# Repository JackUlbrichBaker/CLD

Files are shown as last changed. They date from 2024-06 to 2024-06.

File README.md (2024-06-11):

### Welcome to the Can LED Driver Git repo!

This is an STM32 based smart load switch that is capable of driving up to 60A at 20V (ignoring thermals)
Currently it is just a hardware repo - software TBC.  I know it is overkill but that is more fun than simplicity :seal:
<details open>
<summary>PCB: </summary>



</details>

<details open>
<summary>Schematic: </summary>



</details>

- [x] Hardware schematic
- [x] PCB layed out 
- [ ] PCB routed
- [ ] PCB ordered and populated
- [ ] Software written
- [ ] software tested

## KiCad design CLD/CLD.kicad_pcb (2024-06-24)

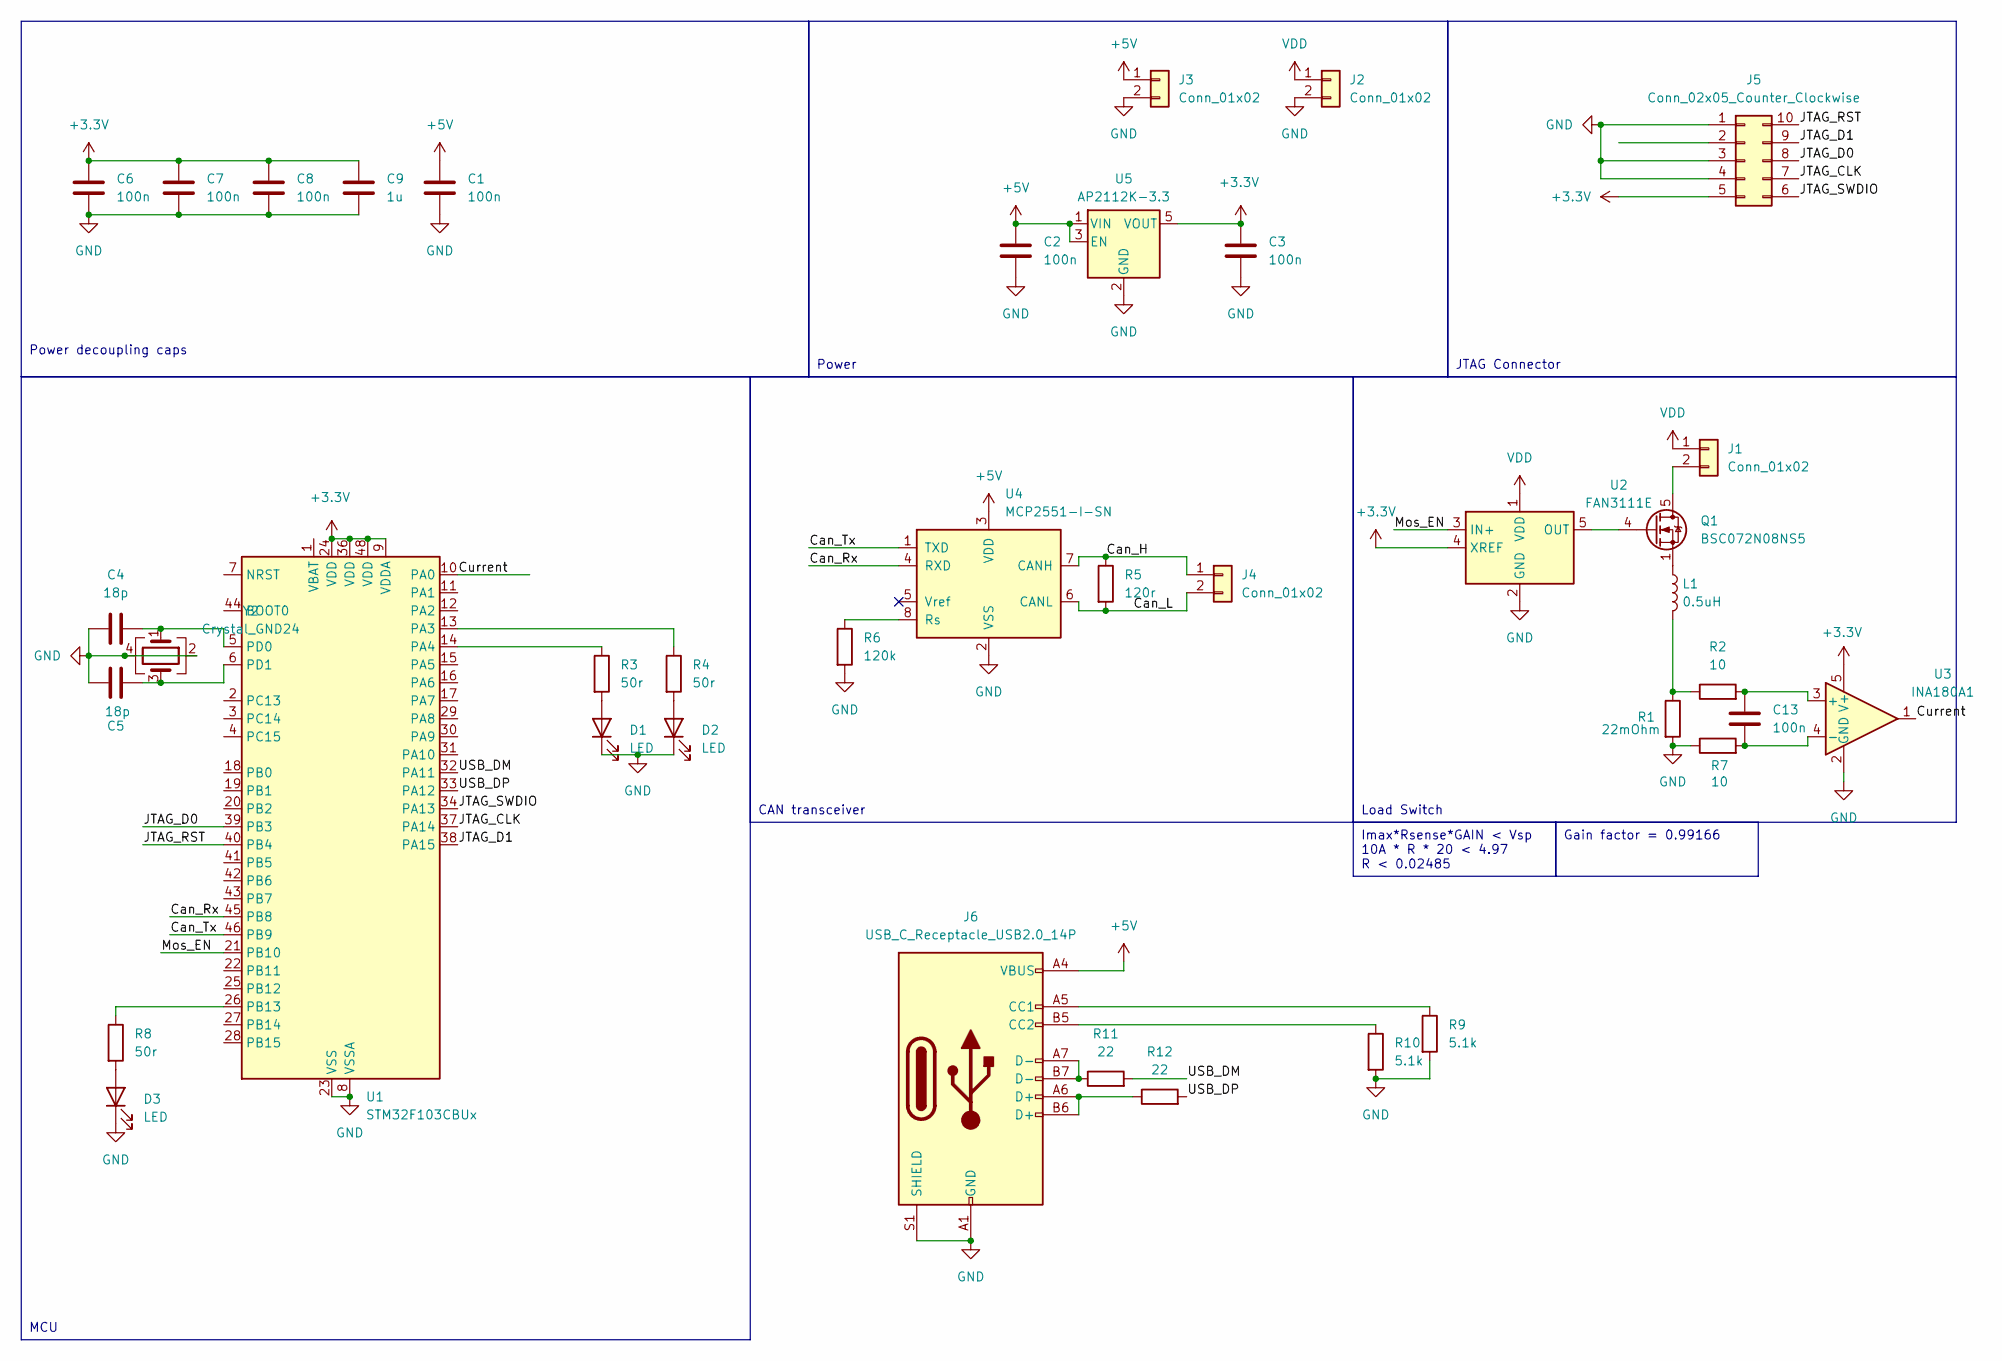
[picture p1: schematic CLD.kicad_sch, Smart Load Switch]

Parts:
C1, C2, C3, C6, C7, C8, C13: 100n; C_0603_1608Metric
C4, C5: 18p; C_0603_1608Metric
C9: 1u; C_0603_1608Metric
D1, D2, D3: LED; D_0603_1608Metric
J1, J2, J3, J4: Conn_01x02; PinHeader_1x02_P2.54mm_Vertical
J5: Conn_02x05_Counter_Clockwise; PinHeader_2x05_P1.27mm_Vertical_SMD
J6: USB_C_Receptacle_USB2.0_14P; USB_C_Receptacle_GCT_USB4105-xx-A_16P_TopMnt_Horizontal
L1: 0.5uH; L_Bourns-SRN8040_8x8.15mm
Q1: BSC072N08NS5; TDSON-8-1
R1: 22mOhm; R_1206_3216Metric
R2, R7: 10; R_0603_1608Metric
R3, R4, R8: 50r; R_0603_1608Metric
R5: 120r; R_0603_1608Metric
R6: 120k; R_0603_1608Metric
R9, R10: 5.1k; R_0603_1608Metric
R11, R12: 22; R_0603_1608Metric
U1: STM32F103CBUx; QFN-48-1EP_7x7mm_P0.5mm_EP5.6x5.6mm
U2: FAN3111E; SOT-23-5
U3: INA180A1; SOT-23-5
U4: MCP2551-I-SN; SOIC-8_3.9x4.9mm_P1.27mm
U5: AP2112K-3.3; SOT-23-5
Y2: Crystal_GND24; Crystal_SMD_Abracon_ABM3C-4Pin_5.0x3.2mm

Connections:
+3.3V: C3.1, C6.1, C7.1, C8.1, C9.1, J5.5, U1.9 (VDDA), U1.24 (VDD), U1.36 (VDD), U1.48 (VDD), U2.4 (XREF), U3.5 (V+), U5.5 (VOUT)
+5V: C1.1, C2.1, J3.1, J6.A4 (VBUS), J6.A9 (VBUS), J6.B4 (VBUS), J6.B9 (VBUS), U4.3 (VDD), U5.1 (VIN), U5.3 (EN); also elsewhere on the board
/Can_H: J4.1, R5.1, U4.7 (CANH)
/Can_L: J4.2, R5.2, U4.6 (CANL)
/Can_Rx: U1.45 (PB8), U4.4 (RXD)
/Can_Tx: U1.46 (PB9), U4.1 (TXD)
/Current: U1.10 (PA0), U3.1
/JTAG_CLK: J5.7, U1.37 (PA14)
/JTAG_D0: J5.8, U1.39 (PB3)
/JTAG_D1: J5.9, U1.38 (PA15)
/JTAG_RST: J5.10, U1.40 (PB4)
/JTAG_SWDIO: J5.6, U1.34 (PA13)
/Mos_EN: U1.21 (PB10), U2.3 (IN+)
/USB_DM: R11.2, U1.32 (PA11)
/USB_DP: R12.2, U1.33 (PA12)
GND: C1.2, C2.2, C3.2, C4.1, C5.1, C6.2, C7.2, C8.2, C9.2, D1.1 (K), D2.1 (K), D3.1 (K), J2.2, J3.2, J5.1, J5.3, J5.4, J6.A1 (GND), J6.A12 (GND), J6.B1 (GND), J6.B12 (GND), J6.S1 (SHIELD), R1.2, R6.2, R7.1, R9.2, R10.2, U1.8 (VSSA), U1.23 (VSS), U1.35 (VSS), U1.47 (VSS), U1.49 (VSS), U2.2 (GND), U3.2 (GND), U4.2 (VSS), U5.2 (GND), Y2.2, Y2.4; also elsewhere on the board
unnamed: D1.2 (A), R3.2
unnamed: D2.2 (A), R4.2
unnamed: D3.2 (A), R8.2
unnamed: J1.2, Q1.5 (D)
unnamed: J6.A5 (CC1), R9.1
unnamed: J6.B5 (CC2), R10.1
unnamed: J6.A6 (D+), J6.B6 (D+), R12.1
unnamed: J6.A7 (D-), J6.B7 (D-), R11.1
unnamed: L1.1, Q1.1 (S), Q1.2 (S), Q1.3 (S)
unnamed: L1.2, R1.1, R2.1
unnamed: Q1.4 (G), U2.5 (OUT)
unnamed: R4.1, U1.13 (PA3)
unnamed: R3.1, U1.14 (PA4)
unnamed: R8.1, U1.26 (PB13)
unnamed: C4.2, U1.5 (PD0), Y2.1
unnamed: C5.2, U1.6 (PD1), Y2.3
unnamed: C13.1, R2.2, U3.3 (+)
unnamed: C13.2, R7.2, U3.4 (-)
unnamed: R6.1, U4.8 (Rs)
VDD: J1.1, J2.1, U2.1 (VDD)

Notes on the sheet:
Imax*Rsense*GAIN < Vsp 10A * R * 20 < 4.97 R < 0.02485
Power
JTAG Connector
Load Switch
MCU
Power decoupling caps
Gain factor = 0.99166
CAN transceiver

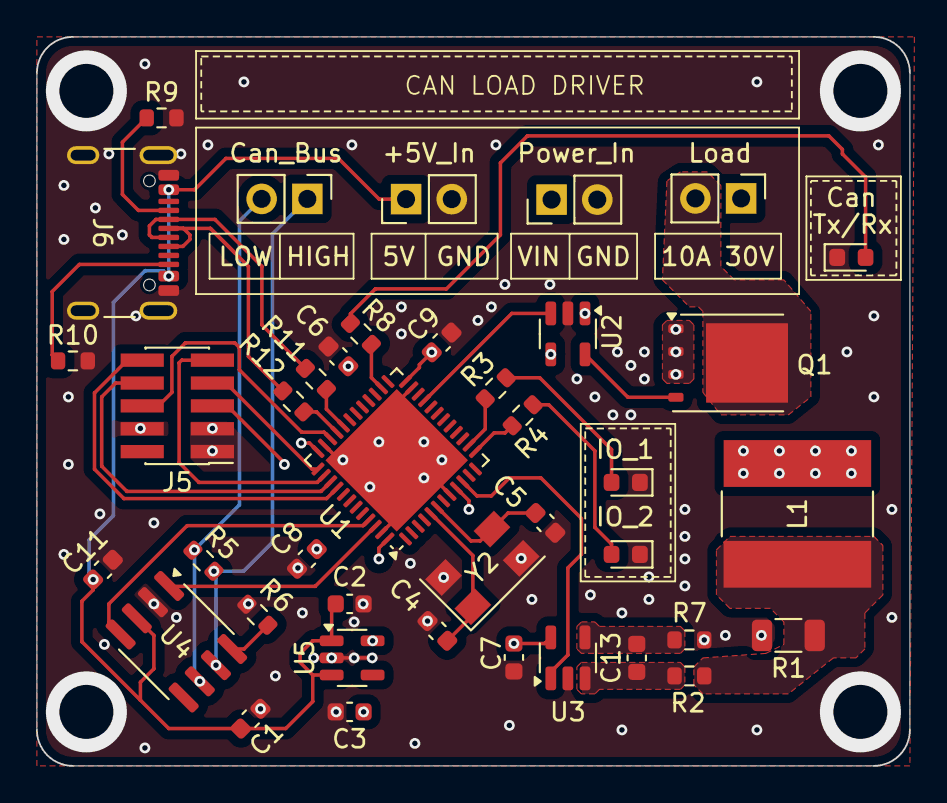
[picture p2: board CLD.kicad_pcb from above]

Board: 4 copper layers, 48.5 x 40.5 mm, 40 parts (0 on the bottom side), 36 nets.

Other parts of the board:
C11: 100n; C_0603_1608Metric

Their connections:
+5V: C11.1; also elsewhere on the board
GND: C11.2; also elsewhere on the board

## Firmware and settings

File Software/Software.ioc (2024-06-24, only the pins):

Mcu.UserName=STM32F103CBUx
PA0-WKUP.GPIO_Label=CURR_IN
PA0-WKUP.Signal=ADCx_IN0
PA11.Signal=USB_DM
PA12.Signal=USB_DP
PA13.Signal=SYS_JTMS-SWDIO
PA14.Signal=SYS_JTCK-SWCLK
PA15.Signal=SYS_JTDI
PB10.Signal=S_TIM2_CH3
PB3.Signal=SYS_JTDO-TRACESWO
PB4.Signal=SYS_NJTRST
PB8.Signal=CAN_RX
PB9.Signal=CAN_TX
PD0-OSC_IN.Signal=RCC_OSC_IN
PD1-OSC_OUT.Signal=RCC_OSC_OUT

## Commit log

2024-05-17 update 17/09
    [CLD.kicad_pcb, CLD.kicad_sch]
2024-05-20 commmit schem v1.0
    [CLD.kicad_pcb, CLD.kicad_sch]
2024-06-08 PCB routed
    [CLD.kicad_pcb, CLD.kicad_sch]
2024-06-11 add USB + crystal
    [CLD.kicad_pcb, CLD.kicad_sch]
2024-06-13 generated gerbers
    [CLD-B_Cu.gbr, CLD-B_Mask.gbr, CLD-B_Silkscreen.gbr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]
2024-06-24 added USB serial resistors oops
    [CLD.kicad_pcb, CLD.kicad_sch]
